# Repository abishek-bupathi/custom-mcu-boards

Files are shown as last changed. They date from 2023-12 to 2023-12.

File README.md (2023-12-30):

<h1 align="center">Custom Microcontroller Boards</h1>

## STM32F1-BMGP
<p align="center">
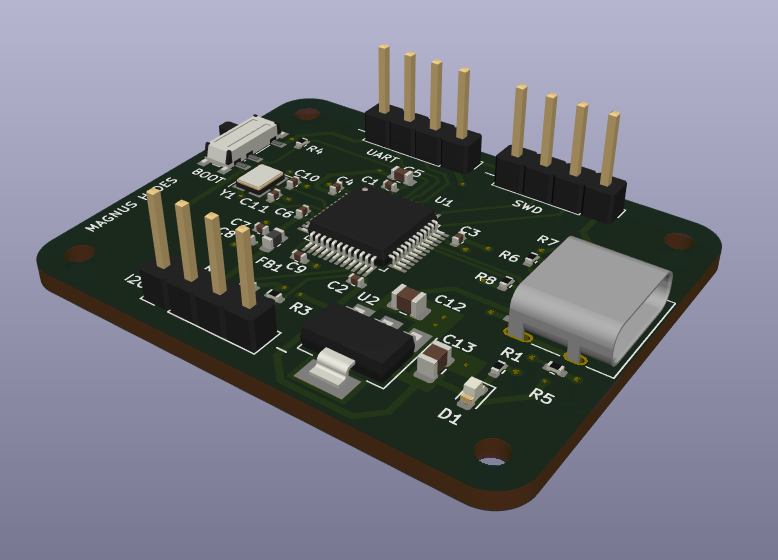
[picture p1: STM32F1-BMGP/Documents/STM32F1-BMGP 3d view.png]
  
</p>

### Features
- Bare Minimum General Purpose (BMGP) board based on STM32F103C8T Microcontroller
- 16 Mhz Clock
- Operating at 3.3 V
- Peripherals: 1xI2C, 1xSPI, 1xUART
- Connectivity: USB 2.0 Type C

### Schematics
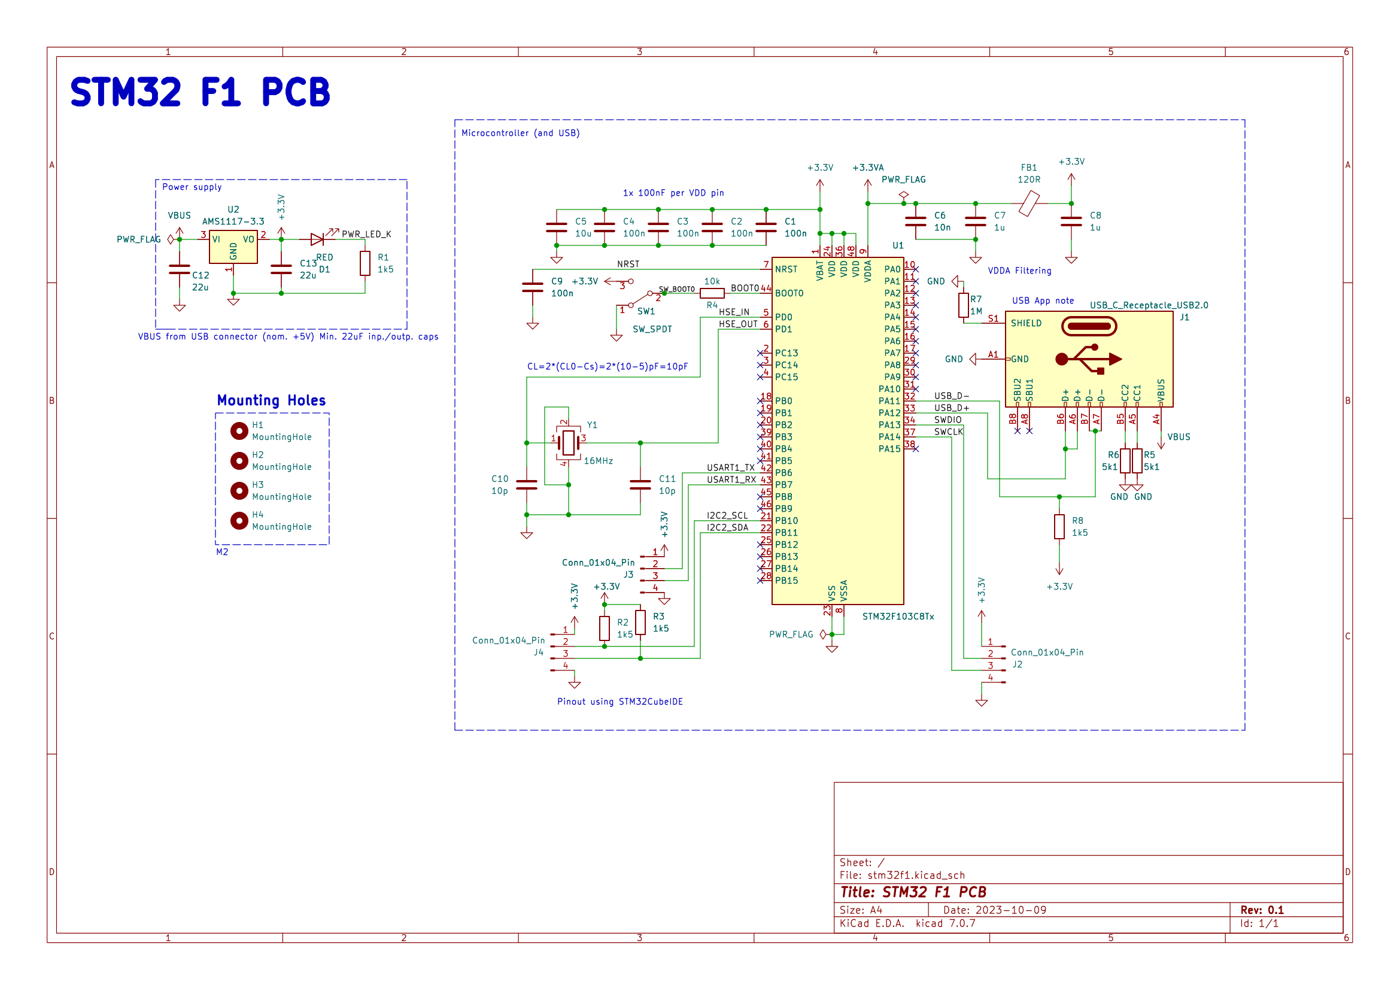
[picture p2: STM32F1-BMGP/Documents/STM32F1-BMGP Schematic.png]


### PCB Layout
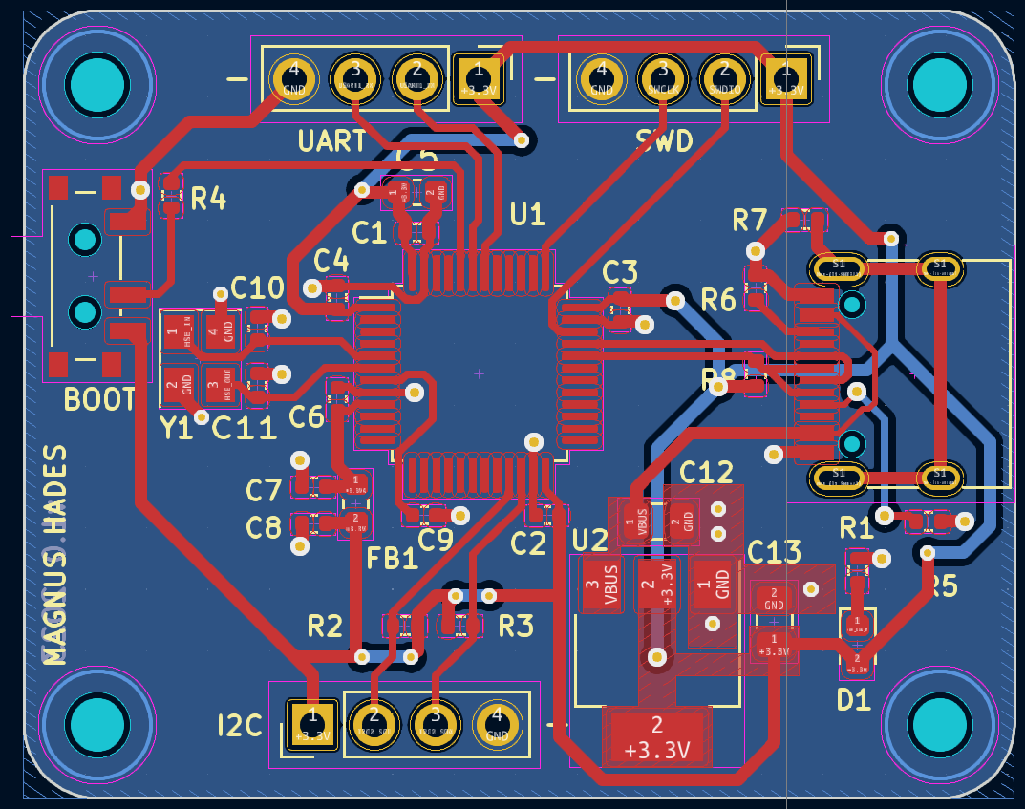
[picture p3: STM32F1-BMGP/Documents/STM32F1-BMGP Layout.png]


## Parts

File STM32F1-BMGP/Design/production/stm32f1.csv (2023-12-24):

Ref | Qnty | Value | Cmp name | Footprint | Description | Vendor | DNP
C1, C2, C3, C4, C9 | 5 | 100n | C | Capacitor_SMD:C_0402_1005Metric | Unpolarized capacitor | TDK | C1005X7R1H104KT000S
C5 | 1 | 10u | C | Capacitor_SMD:C_0603_1608Metric | Unpolarized capacitor | TDK | C1608X7S0J106MT000E
C6 | 1 | 10n | C | Capacitor_SMD:C_0402_1005Metric | Unpolarized capacitor | Darfon Elec | C1005X7R103MGTS
C7, C8 | 2 | 1u | C | Capacitor_SMD:C_0402_1005Metric | Unpolarized capacitor | TDK | C1005X7S1A105KT000E
C10, C11 | 2 | 10p | C | Capacitor_SMD:C_0402_1005Metric | Unpolarized capacitor | Darfon Elec | C1005NPO100DGT
C12, C13 | 2 | 22u | C | Capacitor_SMD:C_0805_2012Metric | Unpolarized capacitor | FH (Guangdong Fenghua Advanced Tech) | 0805X226M6R3NT
D1 | 1 | RED | LED | LED_SMD:LED_0603_1608Metric | Light emitting diode | KINGBRIGHT | APT1608EC
FB1 | 1 | 120R | FerriteBead | Inductor_SMD:L_0603_1608Metric | Ferrite bead | TAI-TECH | HCB1608KF-121T20
J1 | 1 | USB_C_Receptacle_USB2.0 | USB_C_Receptacle_USB2.0 | Connector_USB:USB_C_Receptacle_HRO_TYPE-C-31-M-12 | USB 2.0-only Type-C Receptacle connector | Korean Hroparts Elec | TYPE-C-31-M-12
J2, J3, J4 | 3 | Conn_01x04_Pin | Conn_01x04_Pin | Connector_PinHeader_2.54mm:PinHeader_1x04_P2.54mm_Vertical | Generic connector, single row, 01x04, script generated | Liansheng | PH-00316
R1, R2, R3, R8 | 4 | 1k5 | R | Resistor_SMD:R_0402_1005Metric | Resistor | ROHM Semicon | MCR01MZPF1501
R4 | 1 | 10k | R | Resistor_SMD:R_0402_1005Metric | Resistor | RESI | AECR0402F10K0K9
R5, R6 | 2 | 5k1 | R | Resistor_SMD:R_0402_1005Metric | Resistor | LIZ Elec | CR0402JF0512G
R7 | 1 | 1M | R | Resistor_SMD:R_0402_1005Metric | Resistor | LIZ Elec | CR0402FF1004G
SW1 | 1 | SW_SPDT | SW_SPDT | Button_Switch_SMD:SW_SPDT_PCM12 | Switch, single pole double throw | C&K | PCM12SMTR
U1 | 1 | STM32F103C8Tx | STM32F103C8Tx | Package_QFP:LQFP-48_7x7mm_P0.5mm | STMicroelectronics Arm Cortex-M3 MCU, 64KB flash, 20KB RAM, 72 MHz, 2.0-3.6V, 37 GPIO, LQFP48 | STMicroelectronics | STM32F103C8T6
U2 | 1 | AMS1117-3.3 | AMS1117-3.3 | Package_TO_SOT_SMD:SOT-223-3_TabPin2 | 1A Low Dropout regulator, positive, 3.3V fixed output, SOT-223 | Advanced Monolithic Systems | AMS1117-3.3
Y1 | 1 | 16MHz | Crystal_GND24 | Crystal:Crystal_SMD_3225-4Pin_3.2x2.5mm | Four pin crystal, GND on pins 2 and 4 | Seiko Epson | TSX-3225 16.0000MF18X-AC3

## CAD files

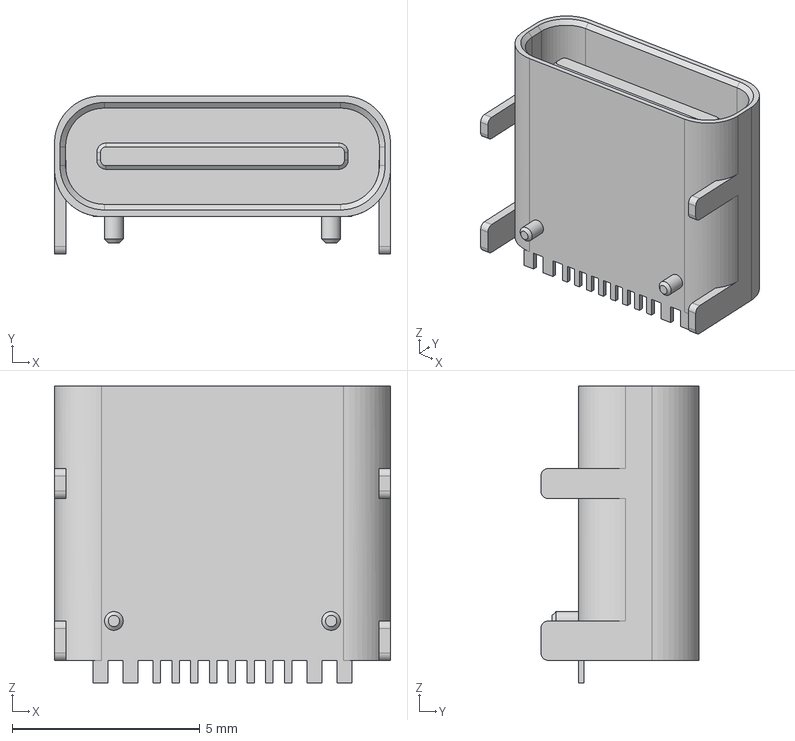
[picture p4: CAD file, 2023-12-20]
STM32F1-BMGP/Design/step-files/HRO TYPE-C-31-M-12.step
8.94 x 4.21 x 7.90 mm

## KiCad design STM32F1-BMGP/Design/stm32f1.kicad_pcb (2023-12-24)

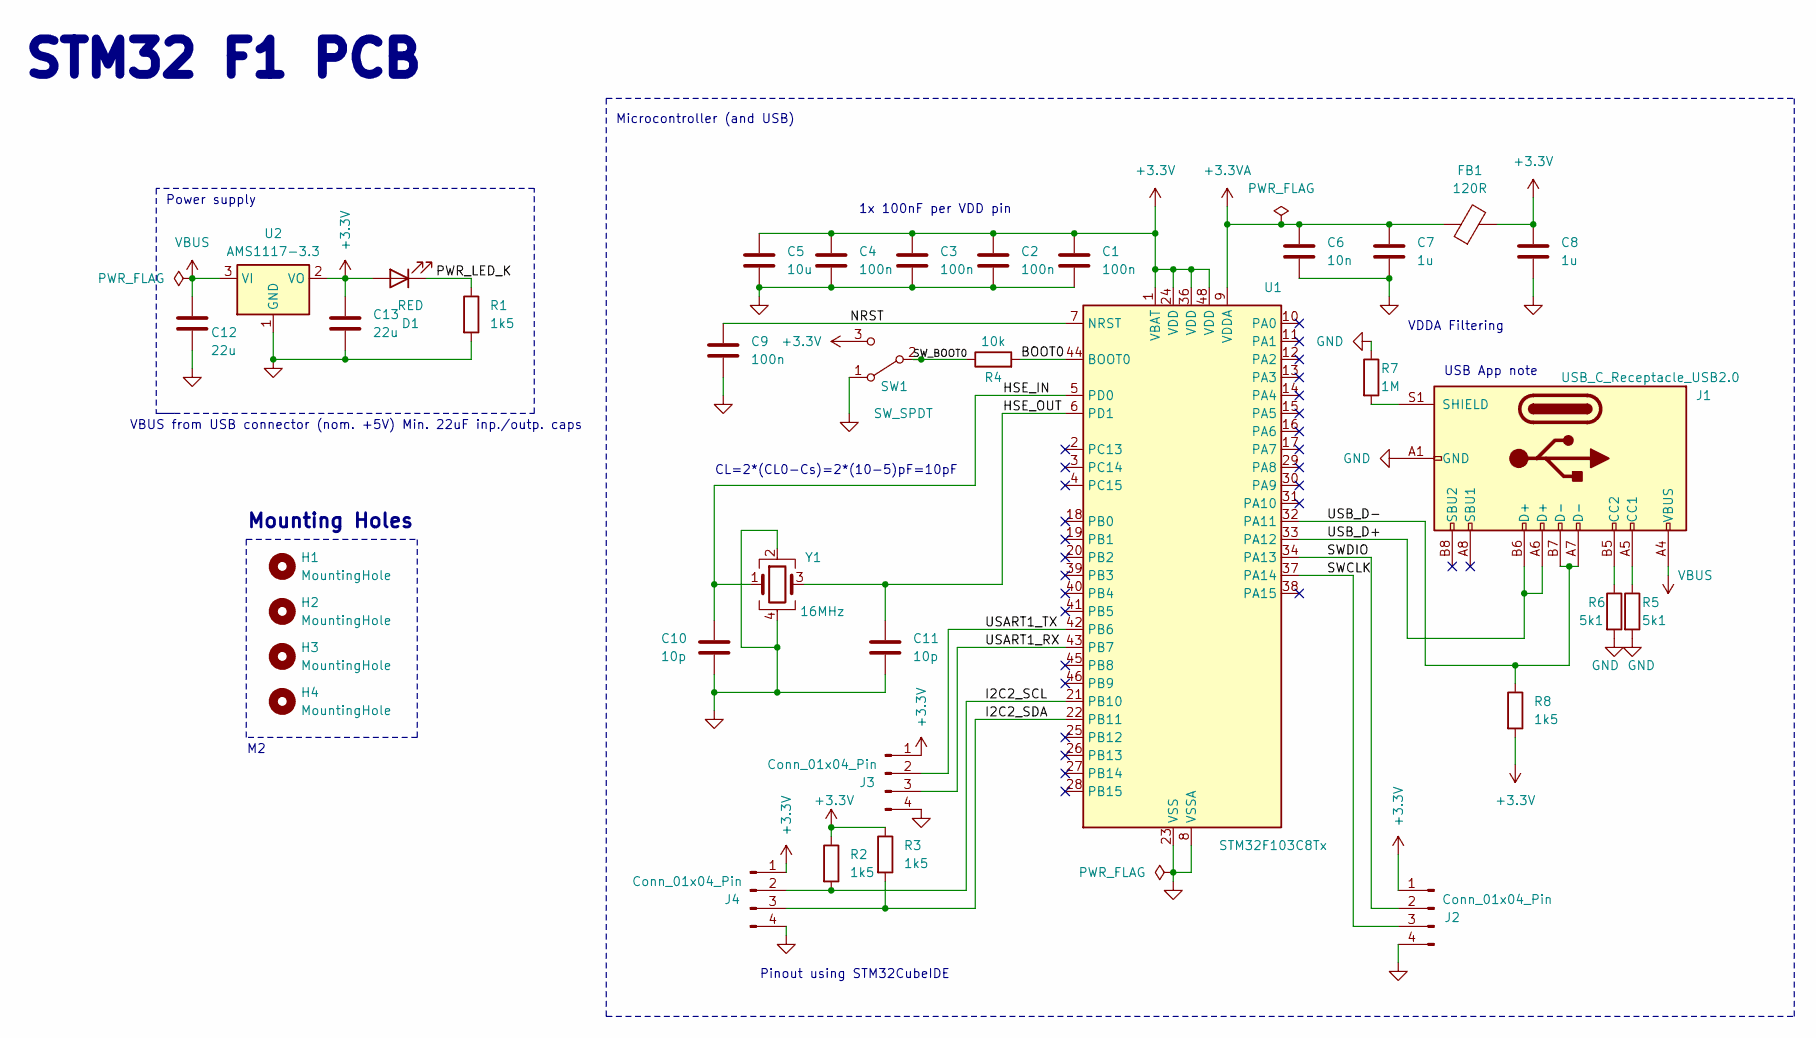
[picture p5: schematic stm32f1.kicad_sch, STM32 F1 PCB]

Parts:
C1, C2, C3, C4, C9: 100n; C_0402_1005Metric
C5: 10u; C_0603_1608Metric
C6: 10n; C_0402_1005Metric
C7, C8: 1u; C_0402_1005Metric
C10, C11: 10p; C_0402_1005Metric
C12, C13: 22u; C_0805_2012Metric
D1: RED; LED_0603_1608Metric
FB1: 120R; L_0603_1608Metric
H1, H2, H3, H4: MountingHole; MountingHole_2.2mm_M2
J1: USB_C_Receptacle_USB2.0; USB_C_Receptacle_HRO_TYPE-C-31-M-12
J2, J3, J4: Conn_01x04_Pin; PinHeader_1x04_P2.54mm_Vertical
R1, R2, R3, R8: 1k5; R_0402_1005Metric
R4: 10k; R_0402_1005Metric
R5, R6: 5k1; R_0402_1005Metric
R7: 1M; R_0402_1005Metric
SW1: SW_SPDT; SW_SPDT_PCM12
U1: STM32F103C8Tx; LQFP-48_7x7mm_P0.5mm
U2: AMS1117-3.3; SOT-223-3_TabPin2
Y1: 16MHz; Crystal_SMD_3225-4Pin_3.2x2.5mm

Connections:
+3.3V: C1.1, C2.1, C3.1, C4.1, C5.1, C8.1, C13.1, D1.2 (A), FB1.2, J2.1, J3.1, J4.1, R2.1, R3.1, R8.2, SW1.3 (C), U1.1 (VBAT), U1.24 (VDD), U1.36 (VDD), U1.48 (VDD), U2.2 (VO)
+3.3VA: C6.1, C7.1, FB1.1, U1.9 (VDDA)
/BOOT0: R4.2, U1.44 (BOOT0)
/HSE_IN: C10.1, U1.5 (PD0), Y1.1
/HSE_OUT: C11.1, U1.6 (PD1), Y1.3
/I2C2_SCL: J4.2, R2.2, U1.21 (PB10)
/I2C2_SDA: J4.3, R3.2, U1.22 (PB11)
/NRST: C9.1, U1.7 (NRST)
/PWR_LED_K: D1.1 (K), R1.1
/SWCLK: J2.3, U1.37 (PA14)
/SWDIO: J2.2, U1.34 (PA13)
/SW_BOOT0: R4.1, SW1.2 (B)
/USART1_RX: J3.3, U1.43 (PB7)
/USART1_TX: J3.2, U1.42 (PB6)
/USB_D+: J1.A6 (D+), J1.B6 (D+), U1.33 (PA12)
/USB_D-: J1.A7 (D-), J1.B7 (D-), R8.1, U1.32 (PA11)
GND: C1.2, C2.2, C3.2, C4.2, C5.2, C6.2, C7.2, C8.2, C9.2, C10.2, C11.2, C12.2, C13.2, J1.A1 (GND), J1.A12 (GND), J1.B1 (GND), J1.B12 (GND), J2.4, J3.4, J4.4, R1.2, R5.2, R6.2, R7.1, SW1.1 (A), U1.8 (VSSA), U1.23 (VSS), U1.35 (VSS), U1.47 (VSS), U2.1 (GND), Y1.2, Y1.4
unnamed: J1.A5 (CC1), R5.1
unnamed: J1.B5 (CC2), R6.1
unnamed: J1.S1 (SHIELD), R7.2
VBUS: C12.1, J1.A4 (VBUS), J1.A9 (VBUS), J1.B4 (VBUS), J1.B9 (VBUS), U2.3 (VI)

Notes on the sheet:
Power supply
VBUS from USB connector (nom. +5V) Min. 22uF inp./outp. caps
Microcontroller (and USB)
1x 100nF per VDD pin
USB App note
VDDA Filtering
CL=2*(CL0-Cs)=2*(10-5)pF=10pF
Pinout using STM32CubeIDE
STM32 F1 PCB
Mounting Holes

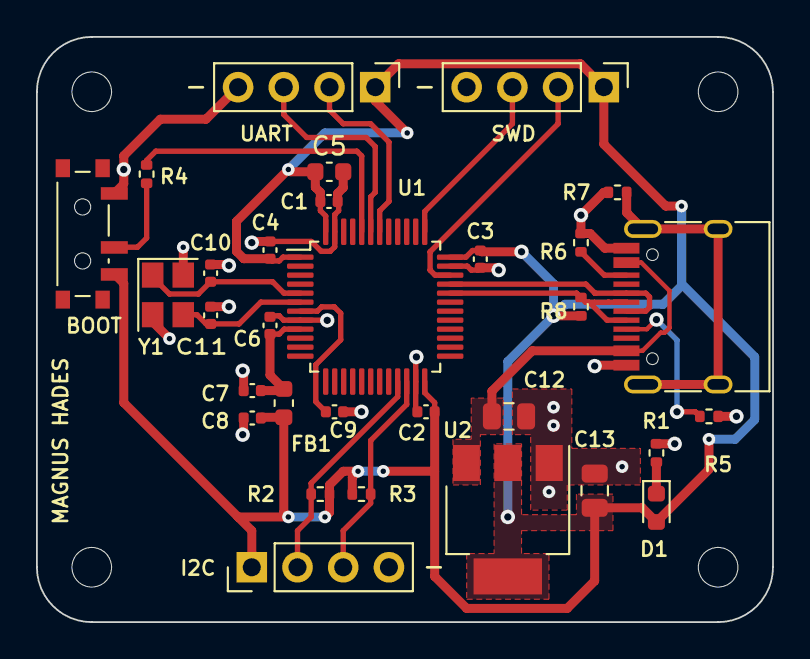
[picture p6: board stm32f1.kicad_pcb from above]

Board: 2 copper layers, 40.9 x 32.5 mm, 35 parts (0 on the bottom side), 21 nets.

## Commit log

2023-10-05 Added power and pinout circuit
    [stm32f1.kicad_sch]
2023-12-08 Completed schematics and added PCB layout
    [1054500101.stp, stm32f1.kicad_pcb, stm32f1.kicad_sch]
2023-12-10 Fine tunes PCB layout and added borders, Started routing
    [stm32f1.kicad_pcb, stm32f1.kicad_sch]
2023-12-20 Completed Board design
    [HRO TYPE-C-31-M-12.step, stm32f1.kicad_pcb, stm32f1.kicad_sch]
2023-12-20 Removed unwanted files
    [1054500101.stp, HRO TYPE-C-31-M-12.step, stm32f1.csv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]
2023-12-21 Added production files
    [stm32f1-B_Cu.gbr, stm32f1-B_Mask.gbr, stm32f1-B_Paste.gbr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]
2023-12-24 Design, BOM, CPL and Gerber files complete
    [stm32f1-B_Cu.gbr, stm32f1-B_Mask.gbr, stm32f1-B_Paste.gbr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]
2023-12-30 Renamed project
    [HRO TYPE-C-31-M-12.step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]
